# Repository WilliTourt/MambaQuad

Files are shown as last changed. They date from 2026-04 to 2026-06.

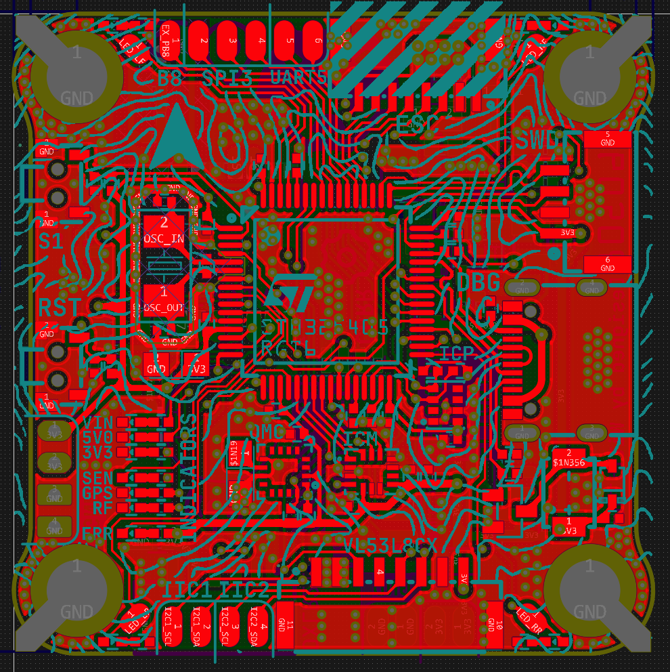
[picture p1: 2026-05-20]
Hardware/Schematic&PCBs/schematic/v1.3/v1.3 top.png

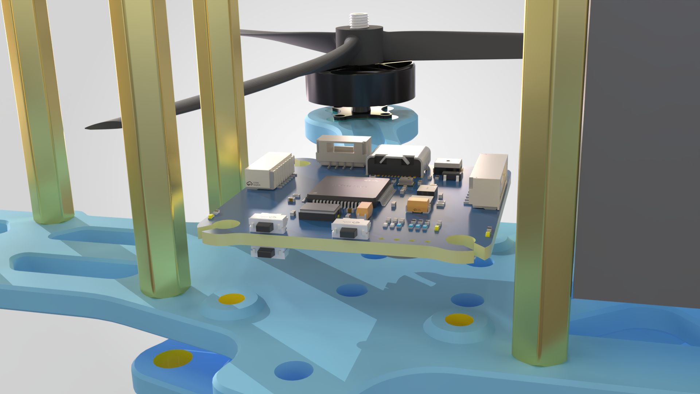
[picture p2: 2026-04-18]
Hardware/3D Models/SolidWorks 2026/Drone Frame/PCB.png

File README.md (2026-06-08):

# MambaQuad UAV

> (Developing)

Mamba out!!!!

### Todos:
- [x] Sensors driver dev
  - [x] Accel & Gyro 陀螺仪
  - [x] Barometer 气压计
  - [x] Magnetometer 磁力计
  - [x] ToF 近距离避障
  - [x] GPS
  - [ ] (Optional) OpticFlow 光流
- [x] PCB Design
- [x] SW Frame Modeling
- [x] General software with RTOS
- [x] Comm. Test
- [ ] ...Physics & PID Tests
- [ ] ...

## Development Environment

- STM32CubeMX + VSCode + EIDE
- FreeRTOS-Cpp-0.5

### Authors:

Willitourt <willitourt@foxmail.com> ;)

Zodiak_Jealousy

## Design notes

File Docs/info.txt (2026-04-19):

This folder contains all datasheets of modules/chips applied on the MambaQuadFC(V1.2) board.

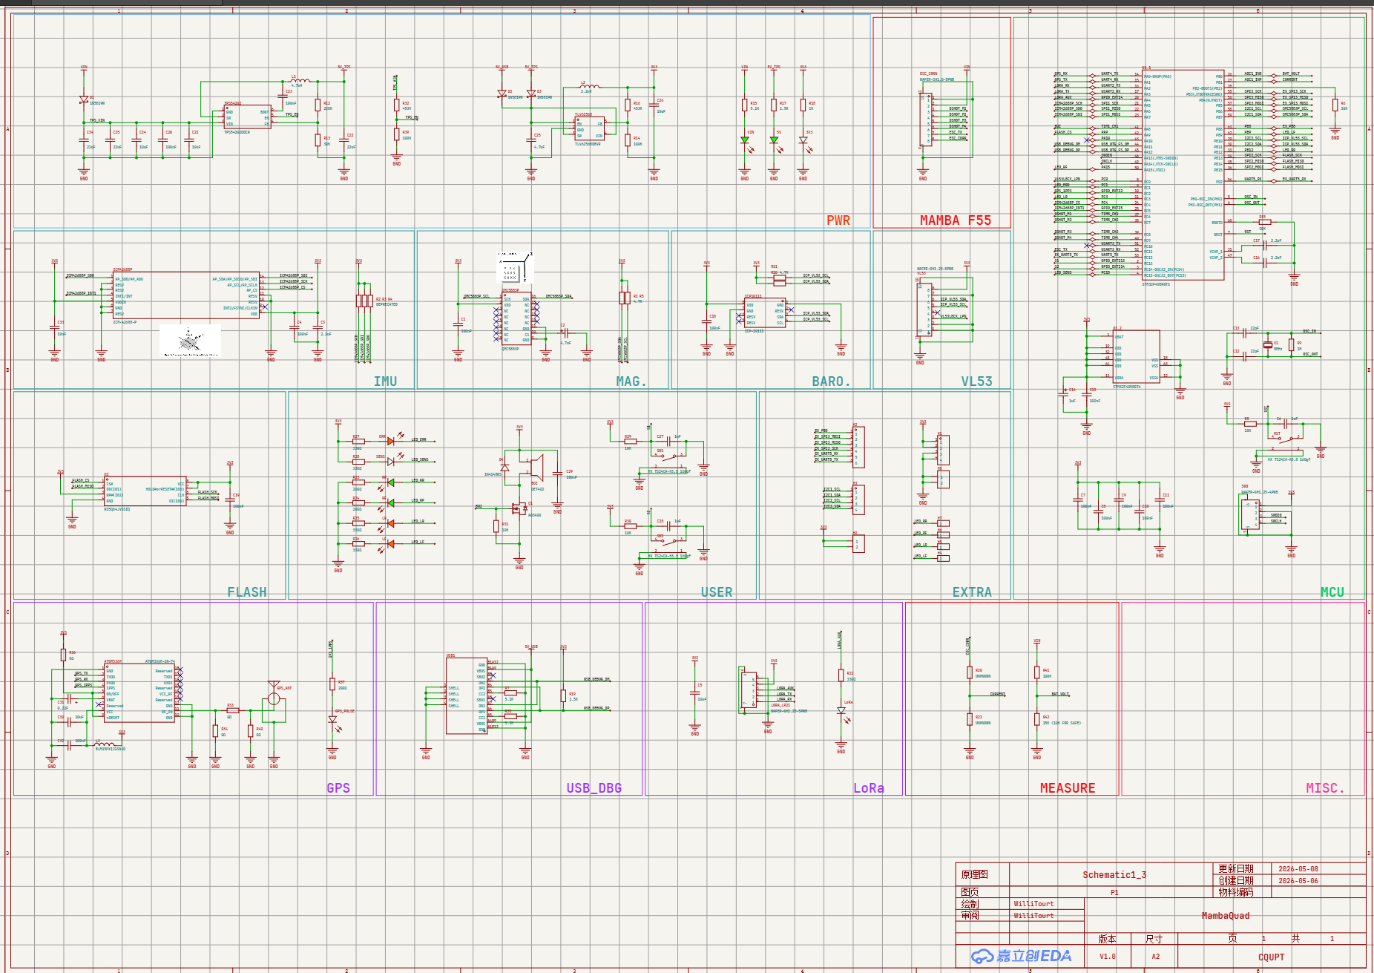
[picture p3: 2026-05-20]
Hardware/Schematic&PCBs/schematic/v1.3/FC v1.3.png

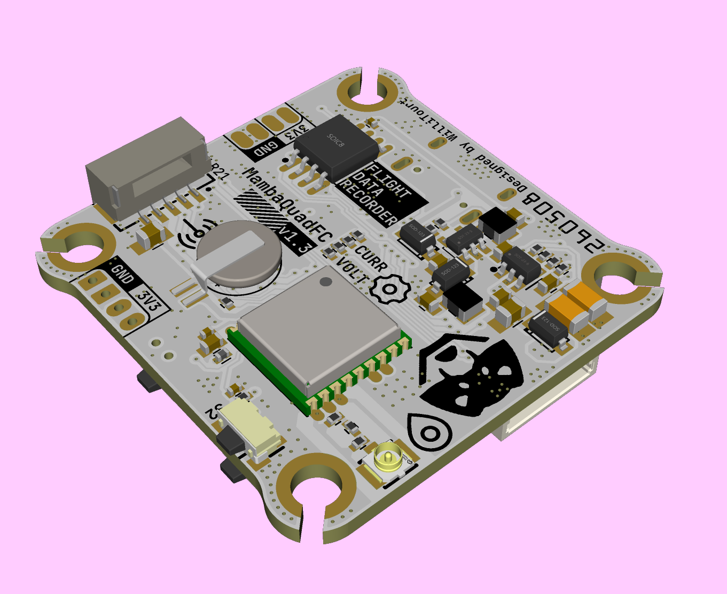
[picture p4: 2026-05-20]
Hardware/Schematic&PCBs/schematic/v1.3/v1.3 3D Preview (2).png

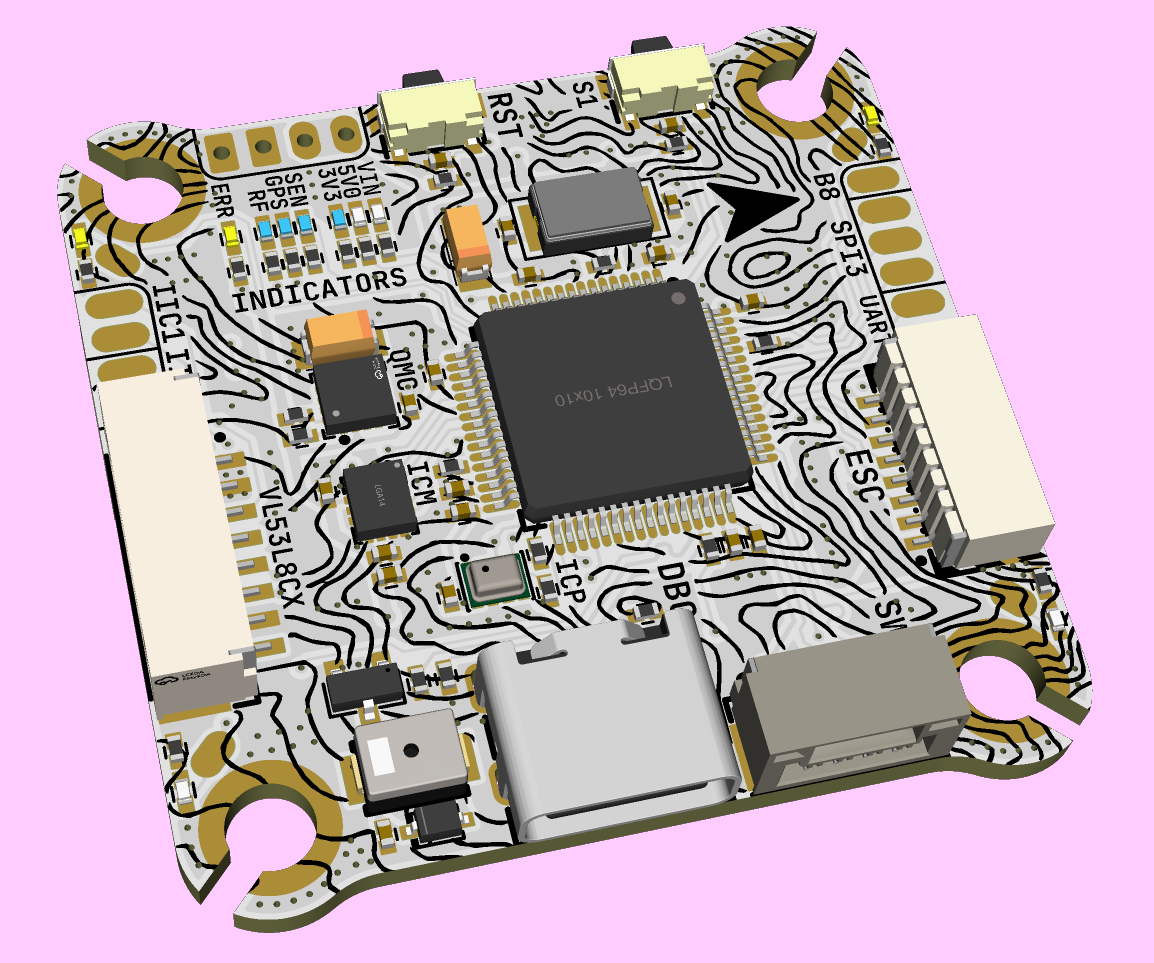
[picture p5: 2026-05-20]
Hardware/Schematic&PCBs/schematic/v1.3/v1.3 3D Preview.png

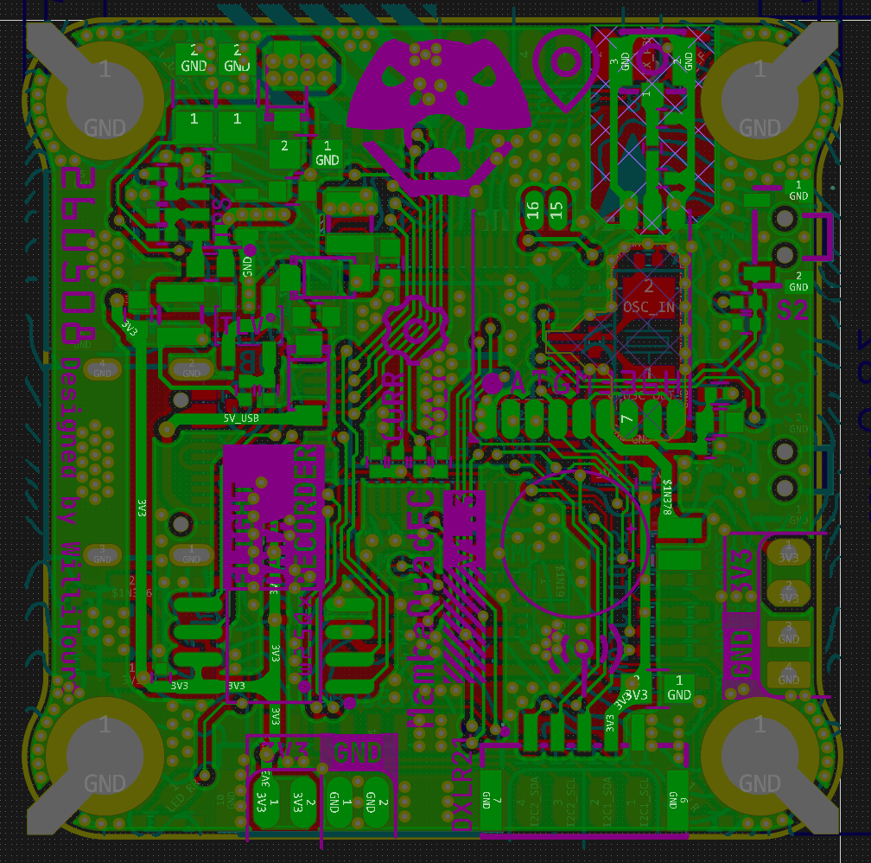
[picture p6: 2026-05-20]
Hardware/Schematic&PCBs/schematic/v1.3/v1.3 bottom.png

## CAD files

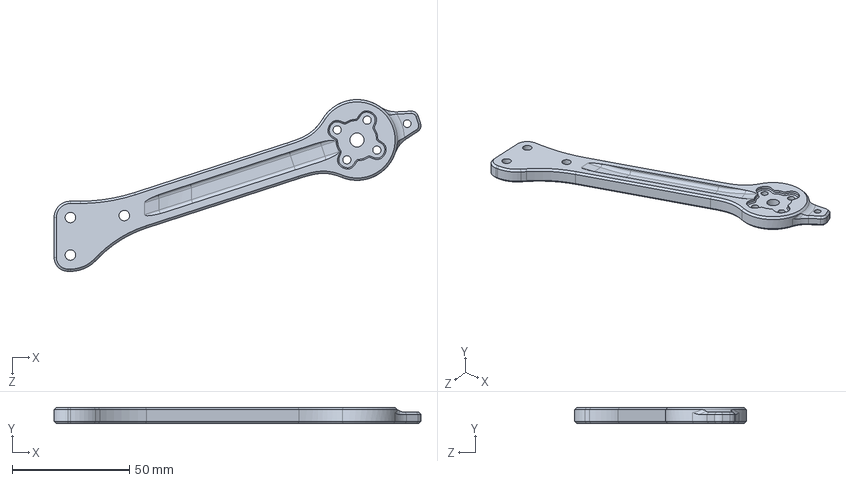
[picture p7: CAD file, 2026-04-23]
Hardware/3D Models/SolidWorks 2026/Drone Frame/Arm FrontRight.SLDPRT
156.6 x 7.00 x 73.3 mm

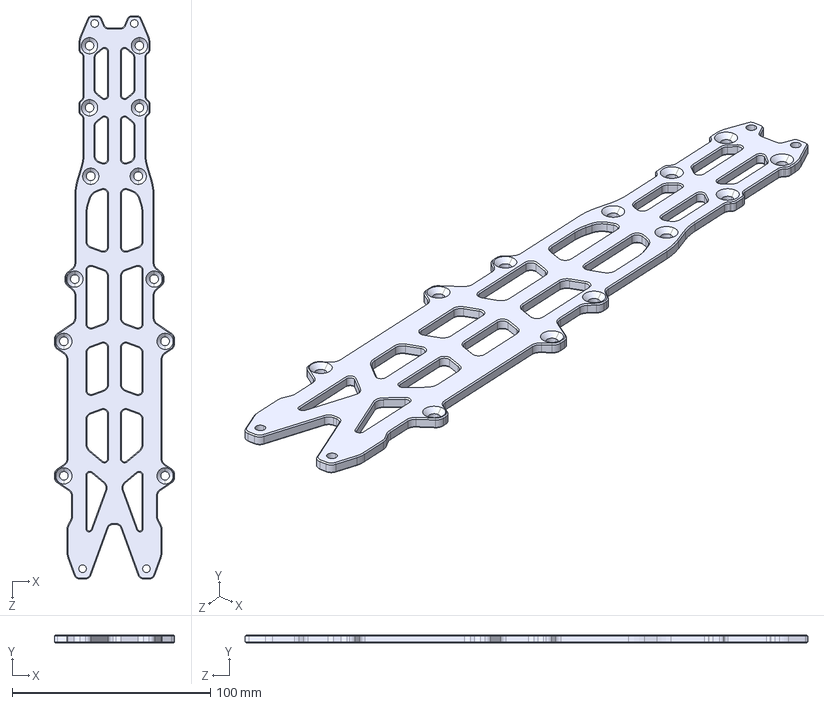
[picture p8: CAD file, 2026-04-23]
Hardware/3D Models/STEPs/Drone Frame/Upper Board.STEP
60.7 x 4.00 x 284.3 mm

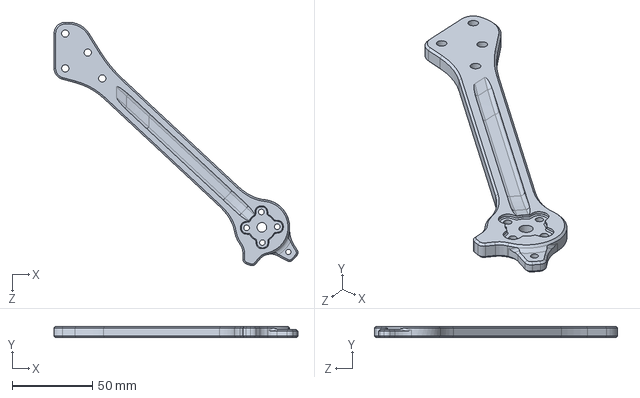
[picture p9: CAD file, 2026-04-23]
Hardware/3D Models/SolidWorks 2026/Drone Frame/Arm BackRight.SLDPRT
151.7 x 7.00 x 151.4 mm

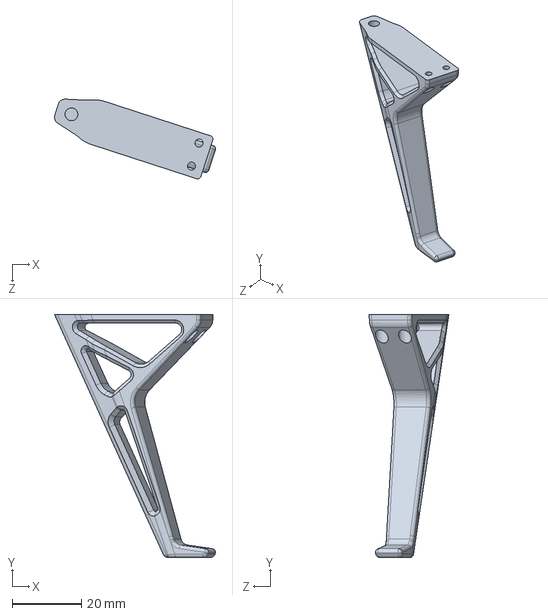
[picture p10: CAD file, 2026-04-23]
Hardware/3D Models/SolidWorks 2026/Drone Frame/Landing Leg.SLDPRT
46.4 x 70.0 x 23.0 mm

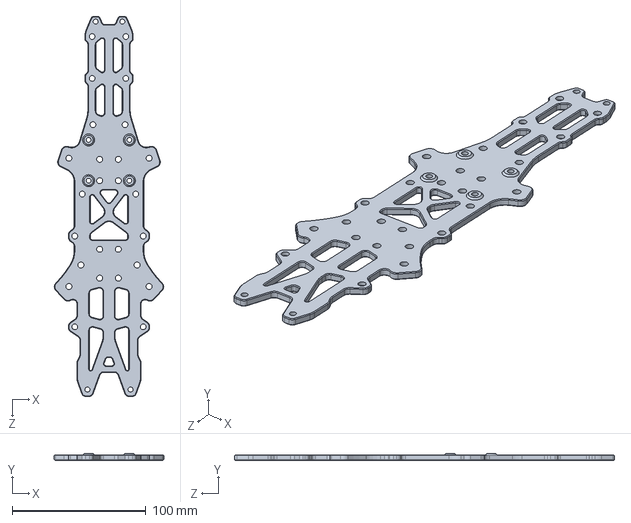
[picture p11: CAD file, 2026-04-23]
Hardware/3D Models/SolidWorks 2026/Drone Frame/Middle Board.SLDPRT
81.9 x 5.00 x 284.3 mm

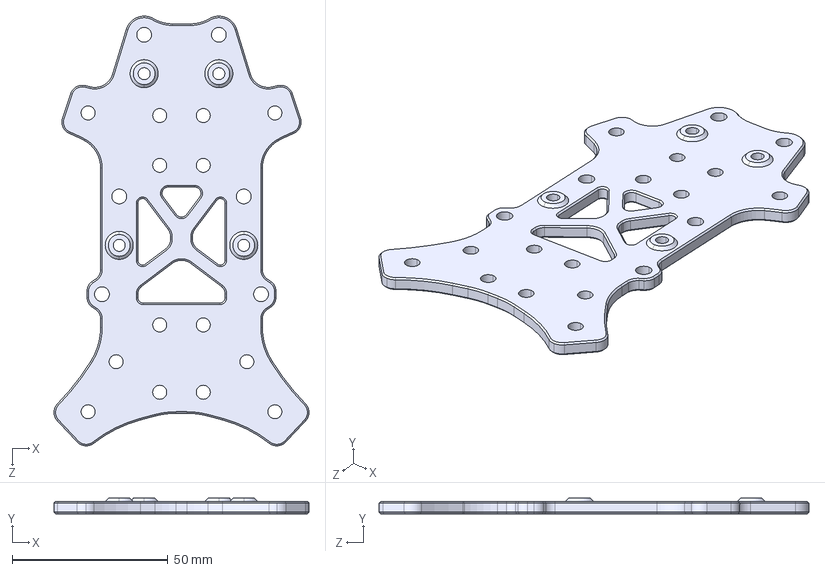
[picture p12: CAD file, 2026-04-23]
Hardware/3D Models/STEPs/Drone Frame/Base Board.STEP
81.9 x 5.00 x 138.1 mm

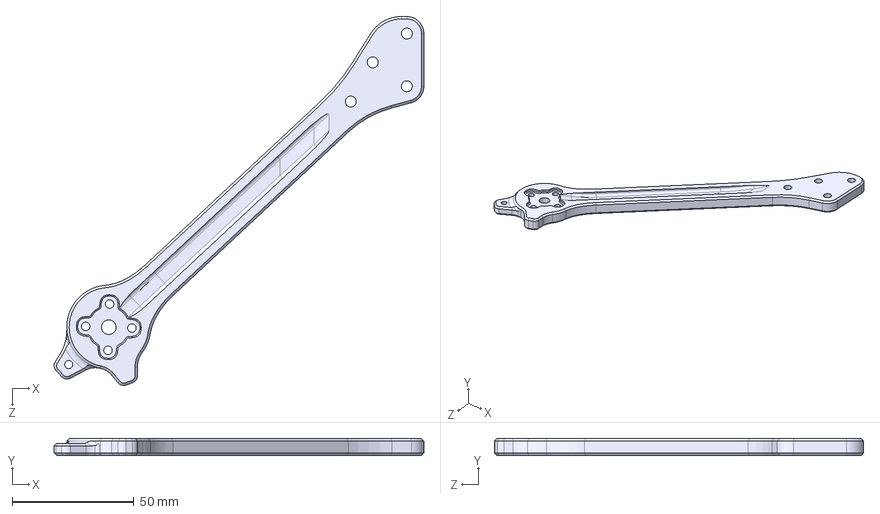
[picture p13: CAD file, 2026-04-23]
Hardware/3D Models/STEPs/Drone Frame/Arm BackLeft.STEP
151.7 x 7.00 x 151.4 mm

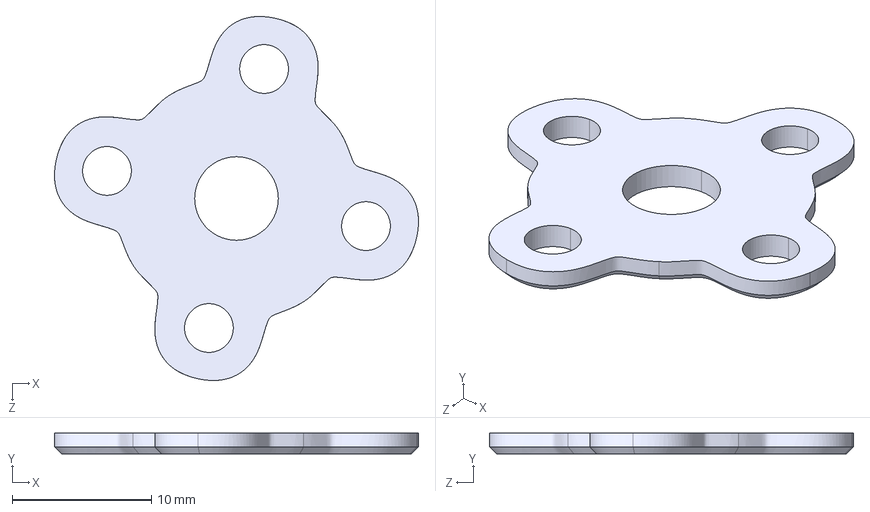
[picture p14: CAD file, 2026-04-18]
Hardware/3D Models/STEPs/Drone Frame/Motor HeatShield.STEP
26.1 x 1.50 x 26.1 mm

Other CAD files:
Hardware/3D Models/STEPs/Drone Frame/Arm FrontRight.STEP
Hardware/3D Models/SolidWorks 2026/Drone Frame/Upper Board.SLDPRT
Hardware/3D Models/STEPs/Drone Frame/Arm FrontLeft.STEP
Hardware/3D Models/STEPs/Drone Frame/Landing Leg.STEP
Hardware/3D Models/SolidWorks 2026/Drone Frame/Arm BackLeft.SLDPRT
Hardware/3D Models/STEPs/Drone Frame/Arm BackRight.STEP
Hardware/3D Models/SolidWorks 2026/Drone Frame/General Size.SLDPRT
Hardware/3D Models/SolidWorks 2026/Drone Frame/Arm FrontLeft.SLDPRT
Hardware/3D Models/STEPs/Drone Frame/Middle Board.STEP
Hardware/3D Models/SolidWorks 2026/Drone Frame/Base Board.SLDPRT
Hardware/3D Models/SolidWorks 2026/Drone Frame/Axisflying AZ2807 Motor - REF.SLDASM
Hardware/3D Models/SolidWorks 2026/Drone Frame/Axisflying AZ2807 Motor - REF.STEP
Hardware/3D Models/SolidWorks 2026/Drone Frame/Lion Battery 5200mah 6S - REF.SLDPRT
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

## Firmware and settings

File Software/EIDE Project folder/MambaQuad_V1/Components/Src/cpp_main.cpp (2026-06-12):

/**
 * @file cpp_main.cpp
 * @version 
 * 
 * @brief 
 * 
 * @CHANGELOG:
 * 
 * 
 */

#include "cpp_main.h"
#include "tasks.h"
#include "dshot.h"

#include "DBGTask.h"

FreeRTOS::Queue<IMUData_t> imuQueue(4);
FreeRTOS::Queue<BaroData_t> baroQueue(2);
FreeRTOS::Queue<MagData_t> magQueue(2);
FreeRTOS::Queue<GPSData_t> gpsQueue(1);
FreeRTOS::Queue<DXLR01::LoraMessage_t> loraQueue(1);

FreeRTOS::Queue<SerialTaskBase::RxPacket> usart2Queue(1);
FreeRTOS::Queue<SerialTaskBase::RxPacket> usart4Queue(1);
FreeRTOS::Queue<GPSData_t> gpsSerialQueue(1);
FreeRTOS::Queue<DXLR01::LoraMessage_t> loraSerialQueue(1);
FreeRTOS::Queue<ControlData_t> ctrlQueue(1);
FreeRTOS::Queue<AttitudeData_t> attQueue(2);


BlinkTask blinkTask;
DBGTask dbgTask(imuQueue, magQueue, baroQueue, gpsQueue, DBGQ, ctrlQueue, attQueue);

IMUTask imuTask(&hspi1, ICM42688P_CS_GPIO_Port, ICM42688P_CS_Pin, imuQueue);
MagTask magTask(&hi2c1, QMC5883P::QMC5883P_Mode::NORMAL, QMC5883P::QMC5883P_Spd::ODR_100HZ, magQueue);
BaroTask baroTask(&hi2c2, ICP10111::ICP10111_MeasurementMode::LOW_NOISE, baroQueue);
AttitudeTask attTask(imuQueue, magQueue, attQueue);

// GPSSerialTask gpsSerialTask(&huart4, usart4Queue, gpsSerialQueue);
// GPSTask gpsTask(gpsSerialTask, gpsSerialQueue, gpsQueue);

// LoraSerialTask loraSerialTask(&huart2, usart2Queue, loraSerialQueue);
// LoraTask loraTask(loraSerialTask, loraSerialQueue, loraQueue, ctrlQueue, attQueue);

DShot m1(&htim8, TIM_CHANNEL_1, DShot::DShotType::DSHOT600);
DShot m2(&htim8, TIM_CHANNEL_2, DShot::DShotType::DSHOT600);
DShot m3(&htim8, TIM_CHANNEL_3, DShot::DShotType::DSHOT600);
DShot m4(&htim8, TIM_CHANNEL_4, DShot::DShotType::DSHOT600);
ControlTask ctrl(m1, m2, m3, m4, &ctrlQueue, &attQueue);

FDRTask fdr(&hspi2, FLASH_CS_GPIO_Port, FLASH_CS_Pin);

void beep() {
	HAL_TIM_PWM_Start(&htim1, TIM_CHANNEL_1);
	__HAL_TIM_SET_COMPARE(&htim1, TIM_CHANNEL_1, 500);
	HAL_Delay(150);
	__HAL_TIM_SET_COMPARE(&htim1, TIM_CHANNEL_1, 0);
	__HAL_TIM_SET_AUTORELOAD(&htim1, 500);
	__HAL_TIM_SET_COMPARE(&htim1, TIM_CHANNEL_1, 250);
	HAL_Delay(150);
	__HAL_TIM_SET_COMPARE(&htim1, TIM_CHANNEL_1, 0);
	__HAL_TIM_SET_AUTORELOAD(&htim1, 333);
	__HAL_TIM_SET_COMPARE(&htim1, TIM_CHANNEL_1, 166);
	HAL_Delay(150);
	__HAL_TIM_SET_COMPARE(&htim1, TIM_CHANNEL_1, 0);
	HAL_TIM_PWM_Stop(&htim1, TIM_CHANNEL_1);
}

extern "C" void dshot_send_all() {
	ControlTask::send();
}

int cpp_main() {

	if (!fdr.init()) {
		HAL_GPIO_WritePin(LED_ERR_GPIO_Port, LED_ERR_Pin, GPIO_PIN_RESET); // turn on error LED
	}

	if (imuTask.init() &&
		baroTask.init() &&
		magTask.init()
		// gpsSerialTask.init() &&
		// loraSerialTask.init()
	) {
		HAL_GPIO_WritePin(LED_SENS_GPIO_Port, LED_SENS_Pin, GPIO_PIN_RESET); // turn on sensor LED
	}

	ctrl.init();
	// loraTask.init(0,0,DXLR01::TransMode::TRANSPARENT,0,0);

	beep();
	FreeRTOS::Kernel::startScheduler();

	while (1);
	return 0;
}

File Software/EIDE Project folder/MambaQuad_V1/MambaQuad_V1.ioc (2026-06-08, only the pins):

Mcu.UserName=STM32F405RGTx
PA0-WKUP.GPIO_Label=GPS_RX
PA0-WKUP.Signal=UART4_TX
PA1.GPIO_Label=GPS_TX
PA1.Signal=UART4_RX
PA11.GPIO_Label=USB_DEBUG_DM
PA11.Signal=USB_OTG_FS_DM
PA12.GPIO_Label=USB_DEBUG_DP
PA12.Signal=USB_OTG_FS_DP
PA13.Signal=SYS_JTMS-SWDIO
PA14.Signal=SYS_JTCK-SWCLK
PA15.GPIO_Label=LED_RF
PA15.Signal=GPIO_Output
PA2.GPIO_Label=LoRa_RX
PA2.Signal=USART2_TX
PA3.GPIO_Label=LoRa_TX
PA3.Signal=USART2_RX
PA4.GPIO_Label=LoRa_AUX
PA4.Signal=GPXTI4
PA5.GPIO_Label=ICM42688P_SCK
PA5.Signal=SPI1_SCK
PA6.GPIO_Label=ICM42688P_MISO
PA6.Signal=SPI1_MISO
PA7.GPIO_Label=ICM42688P_MOSI
PA7.Signal=SPI1_MOSI
PA8.GPIO_Label=BUZ
PA8.Signal=S_TIM1_CH1
PA9.GPIO_Label=FLASH_CS
PA9.Signal=GPIO_Output
PB0.GPIO_Label=BAT_VOLT
PB0.Signal=ADCx_IN8
PB1.GPIO_Label=ESC_CURR
PB1.Signal=ADCx_IN9
PB10.GPIO_Label=ICP_VL53_SCL
PB10.Signal=I2C2_SCL
PB11.GPIO_Label=ICP_VL53_SDA
PB11.Signal=I2C2_SDA
PB12.GPIO_Label=LED_RR
PB12.Signal=GPIO_Output
PB13.GPIO_Label=FLASH_SCK
PB13.Signal=SPI2_SCK
PB14.GPIO_Label=FLASH_MISO
PB14.Signal=SPI2_MISO
PB15.GPIO_Label=FLASH_MOSI
PB15.Signal=SPI2_MOSI
PB3.Signal=SPI3_SCK
PB4.Signal=SPI3_MISO
PB5.Signal=SPI3_MOSI
PB6.GPIO_Label=QMC5883P_SCL
PB6.Signal=I2C1_SCL
PB7.GPIO_Label=QMC5883P_SDA
PB7.Signal=I2C1_SDA
PB9.GPIO_Label=LED_LF
PB9.Signal=GPIO_Output
PC0.GPIO_Label=VL53L8CX_LPn
PC0.Signal=GPIO_Output
PC1.GPIO_Label=LED_ERR
PC1.Signal=GPIO_Output
PC10.Signal=USART3_TX
PC11.GPIO_Label=ESC_TX
PC11.Signal=USART3_RX
PC12.Signal=UART5_TX
PC13-ANTI_TAMP.GPIO_Label=S1
PC13-ANTI_TAMP.Signal=GPXTI13
PC14-OSC32_IN.GPIO_Label=S2
PC14-OSC32_IN.Signal=GPXTI14
PC15-OSC32_OUT.GPIO_Label=LED_SENS
PC15-OSC32_OUT.Signal=GPIO_Output
PC2.GPIO_Label=GPS_1PPS
PC2.Signal=GPXTI2
PC3.GPIO_Label=LED_LR
PC3.Signal=GPIO_Output
PC4.GPIO_Label=ICM42688P_CS
PC4.Signal=GPIO_Output
PC5.GPIO_Label=ICM42688P_INT
PC5.Signal=GPXTI5
PC6.GPIO_Label=DShot_M1
PC6.Signal=S_TIM8_CH1
PC7.GPIO_Label=DShot_M2
PC7.Signal=S_TIM8_CH2
PC8.GPIO_Label=DShot_M3
PC8.Signal=S_TIM8_CH3
PC9.GPIO_Label=DShot_M4
PC9.Signal=S_TIM8_CH4
PD2.Signal=UART5_RX
PH0-OSC_IN.Signal=RCC_OSC_IN
PH1-OSC_OUT.Signal=RCC_OSC_OUT

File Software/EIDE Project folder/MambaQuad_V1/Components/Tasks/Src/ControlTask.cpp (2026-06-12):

#include "ControlTask.h"
#include "DBGTask.h"

volatile uint16_t ControlTask::motor_throttle[4] = {0, 0, 0, 0};

static ControlTask *instance = nullptr;

ControlTask::ControlTask(DShot &m1, DShot &m2, DShot &m3, DShot &m4,
                         FreeRTOS::Queue<ControlData_t> *ctrlQueue,
                         FreeRTOS::Queue<AttitudeData_t> *attQueue) :
    Task(tskIDLE_PRIORITY + 4, 512, "CTRL"),
    _m1(m1), _m2(m2), _m3(m3), _m4(m4),
    _pid_roll_rate(PID_ROLL_RATE_KP, PID_ROLL_RATE_KI, PID_ROLL_RATE_KD),
    _pid_pitch_rate(PID_PITCH_RATE_KP, PID_PITCH_RATE_KI, PID_PITCH_RATE_KD),
    _pid_yaw_rate(PID_YAW_RATE_KP, PID_YAW_RATE_KI, PID_YAW_RATE_KD),
    _pid_roll_angle(PID_ROLL_ANGLE_KP, PID_ROLL_ANGLE_KI, PID_ROLL_ANGLE_KD),
    _pid_pitch_angle(PID_PITCH_ANGLE_KP, PID_PITCH_ANGLE_KI, PID_PITCH_ANGLE_KD),
    _pid_yaw_angle(PID_YAW_ANGLE_KP, PID_YAW_ANGLE_KI, PID_YAW_ANGLE_KD),
    _ctrlQueue(ctrlQueue),
    _attQueue(attQueue) {
    instance = this;
    // _pid_pitch_rate.setDeadzone(0.35);  // 0.35 rad/s = 20.05 deg/s
    // _pid_roll_rate.setDeadzone(0.35);
    // _pid_yaw_rate.setDeadzone(0.35);
    _att = {};
}

void ControlTask::send() {
    static uint8_t idx = 0;
    switch (idx) {
        case 0: instance->_m1.send(motor_throttle[0]); break;
        case 1: instance->_m2.send(motor_throttle[1]); break;
        case 2: instance->_m3.send(motor_throttle[2]); break;
        case 3: instance->_m4.send(motor_throttle[3]); break;
    }
    idx = (idx + 1) & 0B011;
}

bool ControlTask::init() {
    bool ok = _m1.begin() && _m2.begin() && _m3.begin() && _m4.begin();
    return ok;
}

void ControlTask::_arm() {
    motor_throttle[0] = 48;
    motor_throttle[1] = 48;
    motor_throttle[2] = 48;
    motor_throttle[3] = 48;
    _enableSending();
    this->delay(pdMS_TO_TICKS(2000));

    {
        _pid_roll_rate.reset();
        _pid_pitch_rate.reset();
        _pid_yaw_rate.reset();
        _pid_roll_rate.setTarget(0.0f);
        _pid_pitch_rate.setTarget(0.0f);
        _pid_yaw_rate.setTarget(0.0f);

        // 控制循环 ~500Hz → dt=0.002s，必须设对否则 I 项积分速度完全不对
        _pid_roll_rate.setSampleTime(0.002f);
        _pid_pitch_rate.setSampleTime(0.002f);
        _pid_yaw_rate.setSampleTime(0.002f);

        _pid_roll_rate.setIntegralMode(PIDCtrller::IntegralMode_t::Conditional, 0.15f);
        _pid_pitch_rate.setIntegralMode(PIDCtrller::IntegralMode_t::Conditional, 0.15f);
        _pid_yaw_rate.setIntegralMode(PIDCtrller::IntegralMode_t::Conditional, 0.15f);
        _pid_roll_rate.setDerivativeMode(PIDCtrller::DerivativeMode_t::OnMeasurement);
        _pid_pitch_rate.setDerivativeMode(PIDCtrller::DerivativeMode_t::OnMeasurement);
        _pid_yaw_rate.setDerivativeMode(PIDCtrller::DerivativeMode_t::OnMeasurement);
    }

    {
        _pid_roll_angle.reset();
        _pid_pitch_angle.reset();
        _pid_yaw_angle.reset();
        _pid_roll_angle.setTarget(0.0f);
        _pid_pitch_angle.setTarget(0.0f);
        // _pid_yaw_angle.setTarget(0.0f);

        _pid_roll_angle.setSampleTime(0.002f);
        _pid_pitch_angle.setSampleTime(0.002f);
        _pid_yaw_angle.setSampleTime(0.002f);

        _pid_roll_angle.setIntegralMode(PIDCtrller::IntegralMode_t::Conditional, 0.15f);
        _pid_pitch_angle.setIntegralMode(PIDCtrller::IntegralMode_t::Conditional, 0.15f);
    }

    _armed = true;
    DBGQ.sendToBack((uint8_t*)"ControlTask: Motors armed.", 0);
}

void ControlTask::_disarm() {
    motor_throttle[0] = 0;
    motor_throttle[1] = 0;
    motor_throttle[2] = 0;
    motor_throttle[3] = 0;
    this->delay(pdMS_TO_TICKS(3000));
    _disableSending();

    _armed = false;
    DBGQ.sendToBack((uint8_t*)"ControlTask: Motors disarmed.", 0);
}

void ControlTask::_enableSending() {
    HAL_TIM_Base_Start_IT(&htim2);
}

void ControlTask::_disableSending() {
    HAL_TIM_Base_Stop_IT(&htim2);
}

void ControlTask::_handlePIDCmd(uint8_t axis, uint8_t gain, float value) {
    
    PIDCtrller* pid = nullptr;
    const char* axisName = nullptr;

    switch (axis) {
        case 0: pid = &_pid_roll_rate;  axisName = "ROLL_R"; break;
        case 1: pid = &_pid_pitch_rate; axisName = "PITCH_R"; break;
        case 2: pid = &_pid_yaw_rate;   axisName = "YAW_R"; break;
        case 3: pid = &_pid_roll_angle; axisName = "ROLL_A"; break;
        case 4: pid = &_pid_pitch_angle;axisName = "PITCH_A";break;
        case 5: pid = &_pid_yaw_angle;  axisName = "YAW_A"; break;
        default: return;
    }

    float kp = pid->getKp(), ki = pid->getKi(), kd = pid->getKd();
    const char* gainName = nullptr;
    switch (gain) {
        case 0: kp = value; gainName = "KP"; break;
        case 1: ki = value; gainName = "KI"; break;
        case 2: kd = value; gainName = "KD"; break;
        default: return;
    }
    pid->setParams(kp, ki, kd);

    char buf[64];
    snprintf(buf, sizeof(buf),
        "PID %s %s=%.3f (KP=%.3f KI=%.3f KD=%.3f)\r\n",
        axisName, gainName, value, kp, ki, kd);
    DBGQ.sendToBack((uint8_t*)buf, 0);
}
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

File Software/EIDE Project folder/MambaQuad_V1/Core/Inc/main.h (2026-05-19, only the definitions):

#define S1_Pin GPIO_PIN_13
#define S1_GPIO_Port GPIOC
#define S2_Pin GPIO_PIN_14
#define S2_GPIO_Port GPIOC
#define LED_SENS_Pin GPIO_PIN_15
#define LED_SENS_GPIO_Port GPIOC
#define VL53L8CX_LPn_Pin GPIO_PIN_0
#define VL53L8CX_LPn_GPIO_Port GPIOC
#define LED_ERR_Pin GPIO_PIN_1
#define LED_ERR_GPIO_Port GPIOC
#define GPS_1PPS_Pin GPIO_PIN_2
#define GPS_1PPS_GPIO_Port GPIOC
#define LED_LR_Pin GPIO_PIN_3
#define LED_LR_GPIO_Port GPIOC
#define GPS_RX_Pin GPIO_PIN_0
#define GPS_RX_GPIO_Port GPIOA
#define GPS_TX_Pin GPIO_PIN_1
#define GPS_TX_GPIO_Port GPIOA
#define LoRa_RX_Pin GPIO_PIN_2
#define LoRa_RX_GPIO_Port GPIOA
#define LoRa_TX_Pin GPIO_PIN_3
#define LoRa_TX_GPIO_Port GPIOA
#define LoRa_AUX_Pin GPIO_PIN_4
#define LoRa_AUX_GPIO_Port GPIOA
#define ICM42688P_SCK_Pin GPIO_PIN_5
#define ICM42688P_SCK_GPIO_Port GPIOA
#define ICM42688P_MISO_Pin GPIO_PIN_6
#define ICM42688P_MISO_GPIO_Port GPIOA
#define ICM42688P_MOSI_Pin GPIO_PIN_7
#define ICM42688P_MOSI_GPIO_Port GPIOA
#define ICM42688P_CS_Pin GPIO_PIN_4
#define ICM42688P_CS_GPIO_Port GPIOC
#define ICM42688P_INT_Pin GPIO_PIN_5
#define ICM42688P_INT_GPIO_Port GPIOC
#define BAT_VOLT_Pin GPIO_PIN_0
#define BAT_VOLT_GPIO_Port GPIOB
#define ESC_CURR_Pin GPIO_PIN_1
#define ESC_CURR_GPIO_Port GPIOB
#define ICP_VL53_SCL_Pin GPIO_PIN_10
#define ICP_VL53_SCL_GPIO_Port GPIOB
#define ICP_VL53_SDA_Pin GPIO_PIN_11
#define ICP_VL53_SDA_GPIO_Port GPIOB
#define LED_RR_Pin GPIO_PIN_12
#define LED_RR_GPIO_Port GPIOB
#define FLASH_SCK_Pin GPIO_PIN_13
#define FLASH_SCK_GPIO_Port GPIOB
#define FLASH_MISO_Pin GPIO_PIN_14
#define FLASH_MISO_GPIO_Port GPIOB
#define FLASH_MOSI_Pin GPIO_PIN_15
#define FLASH_MOSI_GPIO_Port GPIOB
#define DShot_M1_Pin GPIO_PIN_6
#define DShot_M1_GPIO_Port GPIOC
#define DShot_M2_Pin GPIO_PIN_7
#define DShot_M2_GPIO_Port GPIOC
#define DShot_M3_Pin GPIO_PIN_8
#define DShot_M3_GPIO_Port GPIOC
#define DShot_M4_Pin GPIO_PIN_9
#define DShot_M4_GPIO_Port GPIOC
#define BUZ_Pin GPIO_PIN_8
#define BUZ_GPIO_Port GPIOA
#define FLASH_CS_Pin GPIO_PIN_9
#define FLASH_CS_GPIO_Port GPIOA
#define USB_DEBUG_DM_Pin GPIO_PIN_11
#define USB_DEBUG_DM_GPIO_Port GPIOA
#define USB_DEBUG_DP_Pin GPIO_PIN_12
#define USB_DEBUG_DP_GPIO_Port GPIOA
#define LED_RF_Pin GPIO_PIN_15
#define LED_RF_GPIO_Port GPIOA
#define ESC_TX_Pin GPIO_PIN_11
#define ESC_TX_GPIO_Port GPIOC
#define QMC5883P_SCL_Pin GPIO_PIN_6
#define QMC5883P_SCL_GPIO_Port GPIOB
#define QMC5883P_SDA_Pin GPIO_PIN_7
#define QMC5883P_SDA_GPIO_Port GPIOB
#define LED_LF_Pin GPIO_PIN_9
#define LED_LF_GPIO_Port GPIOB

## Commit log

2025-12-09 Add VL53L8CX ToF sensor library
2026-02-08 Add PCB schematics, EasyEDA projects and gerbers
    Add PCB design sources and output files for MambaV1 series boards. Includes EasyEDA project files, gerber archives, and schematic/board images.
2026-02-22 Updated sensor drivers
2026-02-22 Uploaded V1 VSCode EIDE project folder
    so far, project has completed all sensor reads, partly completed data processing, waiting to test ESC and communication modules
2026-02-22 Move task implementations out of header
    Refactor tasks: move DBGTask::taskFunction and several task constructors (DBGTask, IMUTask, MagTask, BaroTask) from Components/Inc/tasks.h into Components/Src/tasks.cpp. Header now contains only decl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
2026-04-04 Add ATGM336H GNSS driver and NMEA lib
    Introduce ATGM336H component and embedded NMEA library: adds ATGM336H C++ wrapper (ATGM336H.h/.cpp) that parses NMEA sentences and converts UTC to Beijing time, plus a full nmeaLib (parser, generator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
2026-04-15 Add MotorTask and enable DShot DMA/FIFO
    Add MotorTask (MotorTask.h/cpp) and register motor1 in cpp_main to drive ESCs via DShot on TIM8. Clamp throttle values in DShot::send and include a simple test pattern in the task. Configure TIM8 DMA channels for word alignment and enable FIFO/threshold/burst settings to support DShot transfers. Remove TIM2 usage (init, MSP, externs) and associated EXTI handlers/NVIC setup (EXTI9_5/EXTI15_10) and calls, simplifying GPIO/ISR plumbing. Adjust Blink task timing to a short on/long off pattern. Update project .ioc and Makefile metadata and change SysTick/TIM7 interrupt priorities to 0 to match RTOS timing requirements.
    [MambaQuad_V1.ioc, cpp_main.cpp, dshot.cpp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]
2026-04-16 Motor tested ;)
2026-04-17 Add SolidWorks drone frame models
    [Arm BackLeft.SLDPRT, Arm BackRight.SLDPRT, Arm FrontLeft.SLDPRT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]
2026-04-18 Updated 3D source files
    [Arm BackLeft.SLDPRT, Arm BackRight.SLDPRT, Arm FrontLeft.SLDPRT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]
2026-04-18 Uploaded drone frame STEP files
    [Arm BackLeft.STEP, Arm BackRight.STEP, Arm FrontLeft.STEP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]
2026-04-19 Add datasheet PDFs for MambaQuadFC
    Add a Docs folder with datasheet PDFs and an info.txt for the MambaQuadFC (v1.2) board. Includes ATGM336H, DX-LR01 (general and USART), TLV62568, and TPS54202 datasheets, plus info.txt describing the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
2026-04-23 Uploaded FC v1.2 PCB images
2026-04-23 Separated the LoRa module driver
2026-04-23 fixed imu 'g' macro compilation error
    [IMUTask.cpp, icm42688p.cpp, icm42688p.h]
2026-04-23 Updated STEP Models
    [Arm BackLeft.STEP, Arm BackRight.STEP, Arm FrontLeft.STEP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]
2026-04-23 Updated SolidWorks models
    [Arm BackLeft.SLDPRT, Arm BackRight.SLDPRT, Arm FrontLeft.SLDPRT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]
2026-05-20 Add EasyEDA projects, gerber and v1.3 schematics
    Add new EasyEDA project files (.epro2) for Prototype and V1.1–V1.3 (2026-05-20) and include gerber archive for MambaQuad FC v1.3. Remove outdated ProPrj_MambaQuad_2026-04-23.epro. Reorganize existing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
2026-05-21 fix: dshot.h pragma once
    [dshot.cpp, dshot.h]
2026-05-21 motor control update
2026-06-08 FIX: UARTx GLOBAL INTERRUPT NOT OPENED
    This results in the inability to trigger an interrupt after receiving a small amount of data until the HC or TC interrupt is forcibly triggered by the DMA. This explains why the previous large volume of GPS data could continuously trigger TC, while the lora serial port remained unresponsive
    [ControlTask.cpp, DBGTask.cpp, LoraTask.cpp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]
2026-06-09 Implemented WIRELESS DEBUG, ready to do pid test
2026-06-10 ROLL-RATE PID TEST COMPLETE
    P = 160, I = 120, D = 2.2
2026-06-11 angle rate PID test completed
2026-06-12 PID ROLL ANGLE LOOP TUNED

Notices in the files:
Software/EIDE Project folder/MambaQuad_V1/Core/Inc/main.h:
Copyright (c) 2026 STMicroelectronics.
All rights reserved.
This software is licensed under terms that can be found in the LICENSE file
